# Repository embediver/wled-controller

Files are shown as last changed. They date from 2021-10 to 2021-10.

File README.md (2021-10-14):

# A simple, ESP-07 based, controller for NeoPixel LED's 
Designed to work with all kinds of single wire adressable NeoPixel LEDs and ATX Power supplies.

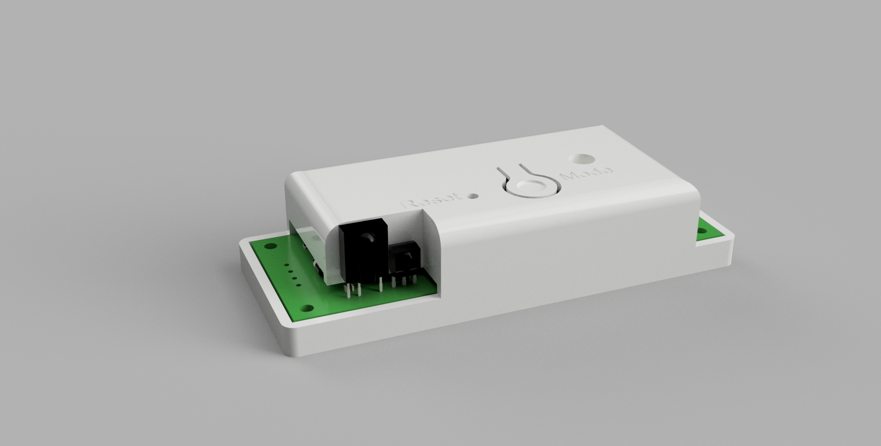
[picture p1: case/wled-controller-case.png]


* Works great with [WLED](https://github.com/Aircoookie/WLED)
* Support for IR Remotes
* Two-Layer PCB designed for home production
* 74HTC00 as Levelshifter
* Output to Toggle PS-ON pin of ATX power supplies
* Over voltage protection on I/O ports

It's intended to be uesed with ATX power supplies (since they are so easy availible), where it can be driven over the 5V always-on rail.
By powering the LED's with the other Rails, they can be switched off together with the PS.

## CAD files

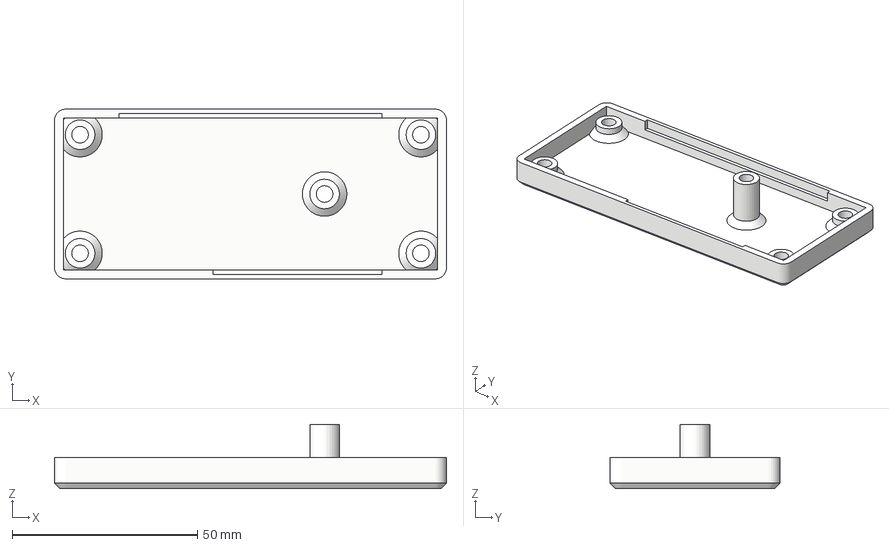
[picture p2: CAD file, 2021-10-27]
case/bottom.3mf
105.8 x 45.8 x 17.4 mm

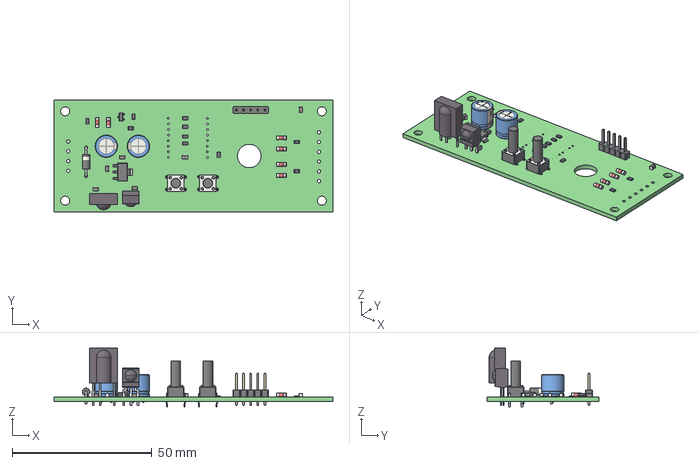
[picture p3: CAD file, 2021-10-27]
wled-controller.step
100.0 x 40.0 x 21.0 mm

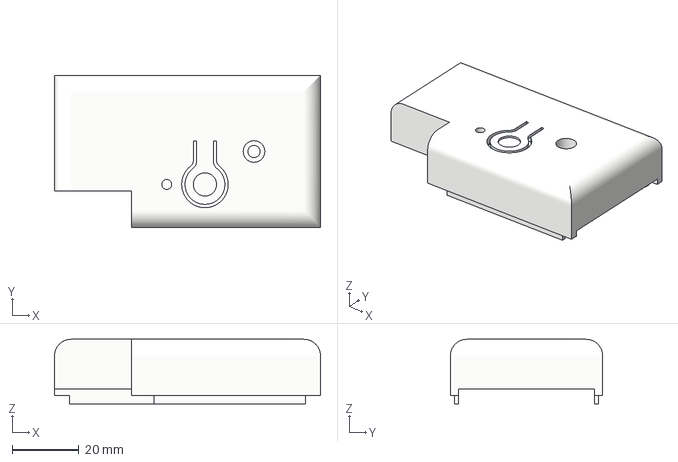
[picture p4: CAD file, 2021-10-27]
case/cover.3mf
80.0 x 45.8 x 19.4 mm

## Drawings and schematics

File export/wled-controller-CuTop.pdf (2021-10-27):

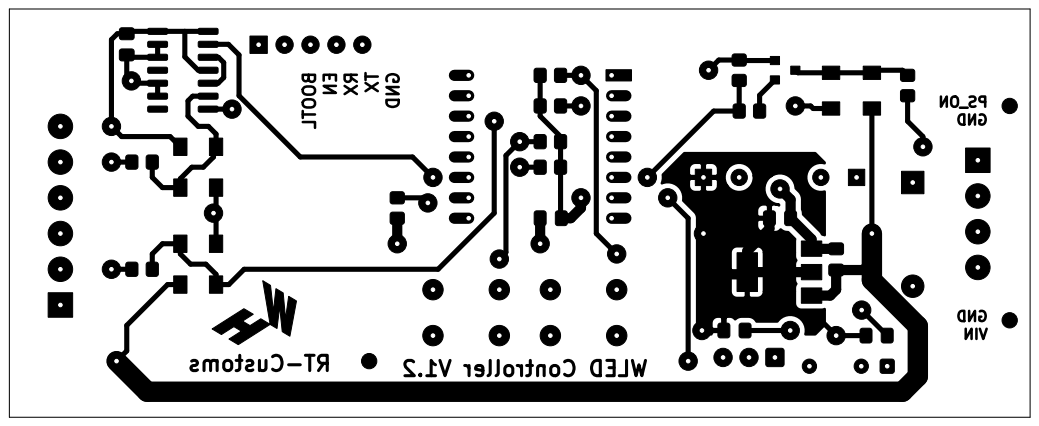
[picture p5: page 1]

PS_ON GND RT-Customs WLED Controller V1.2 BOOTL ENRXTXGND

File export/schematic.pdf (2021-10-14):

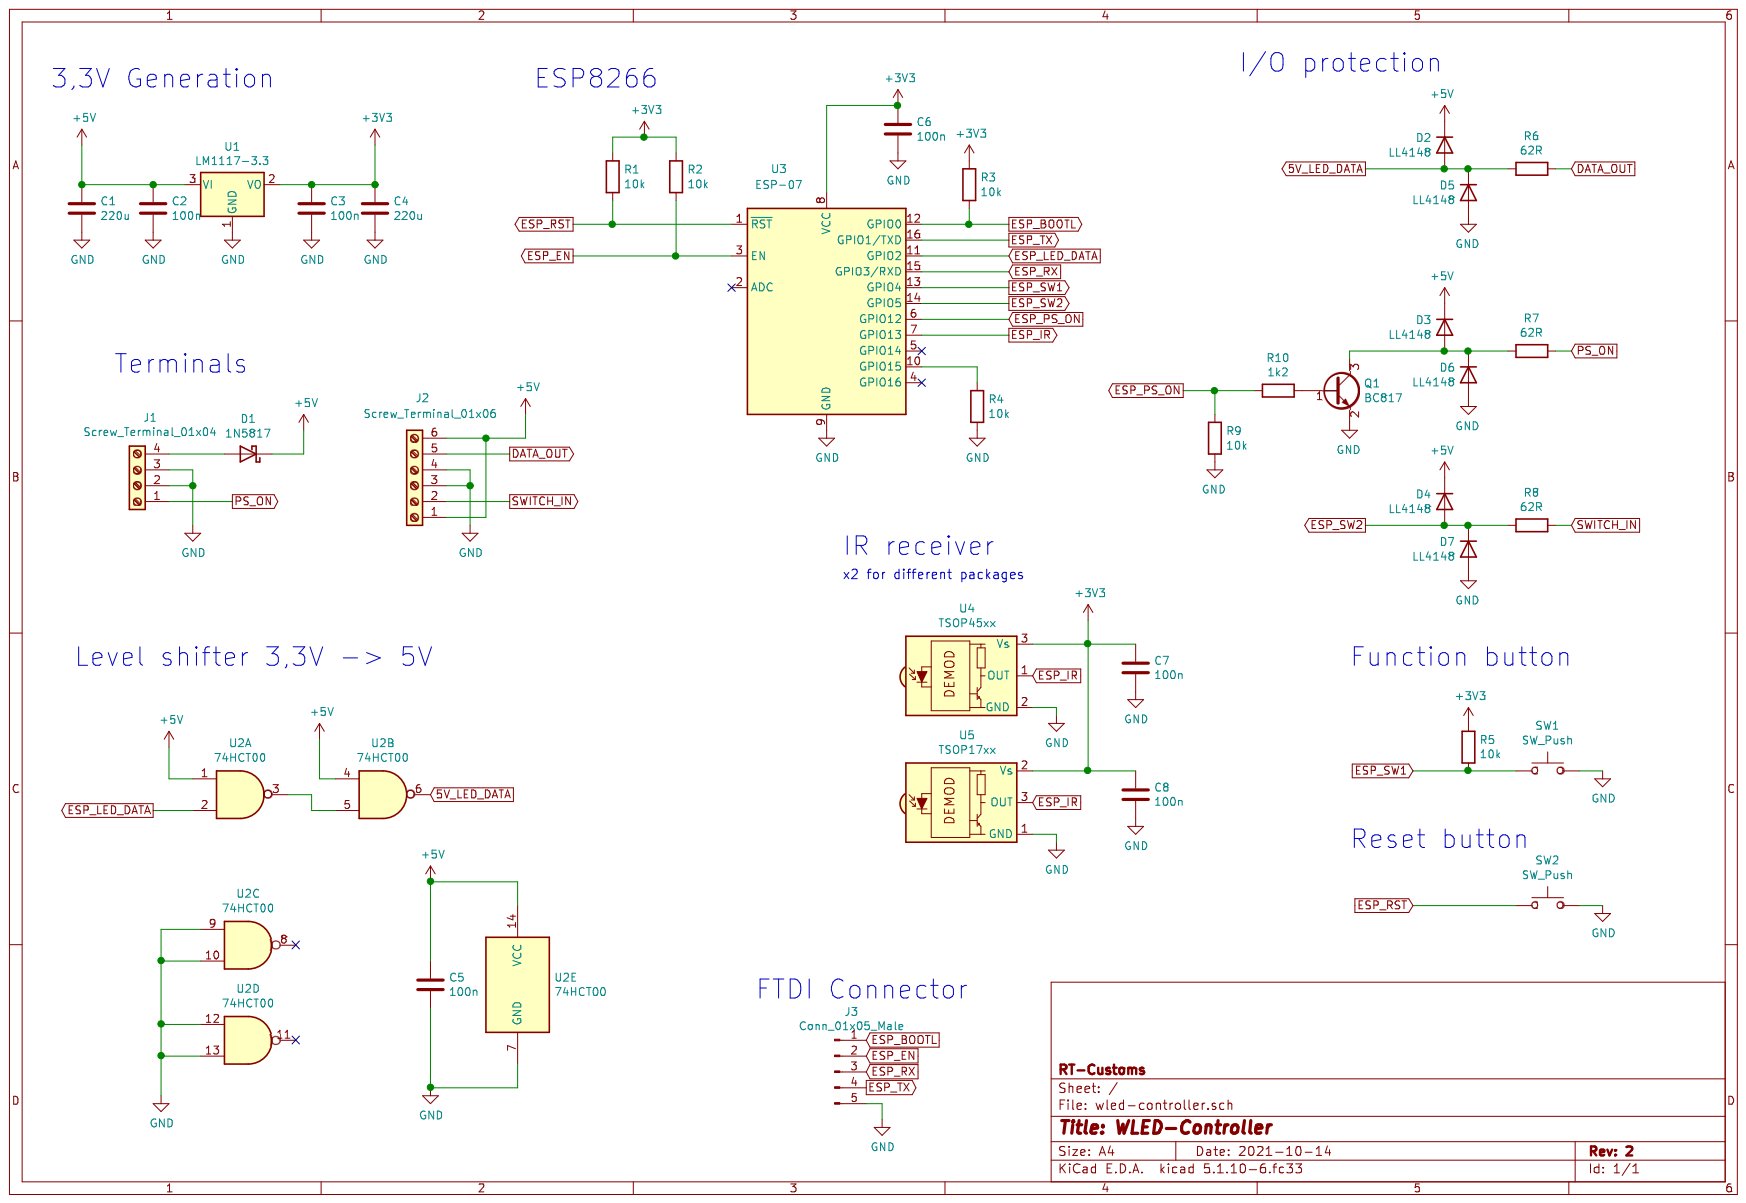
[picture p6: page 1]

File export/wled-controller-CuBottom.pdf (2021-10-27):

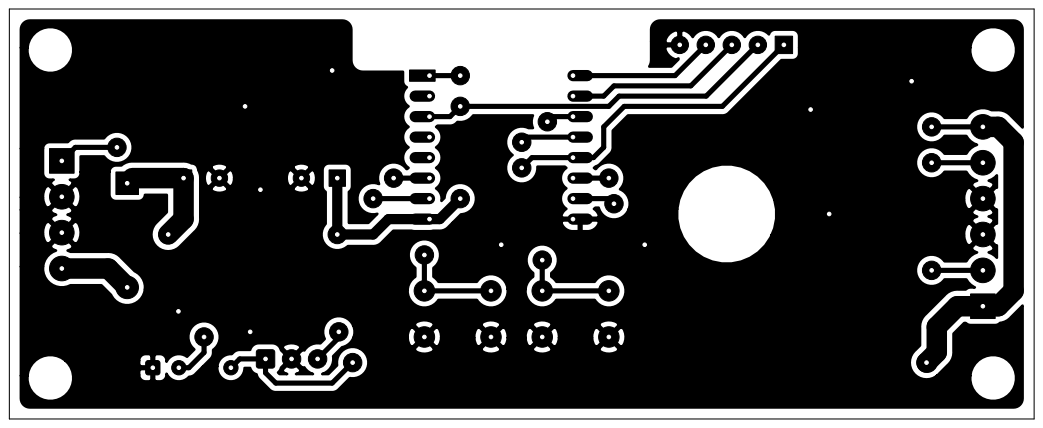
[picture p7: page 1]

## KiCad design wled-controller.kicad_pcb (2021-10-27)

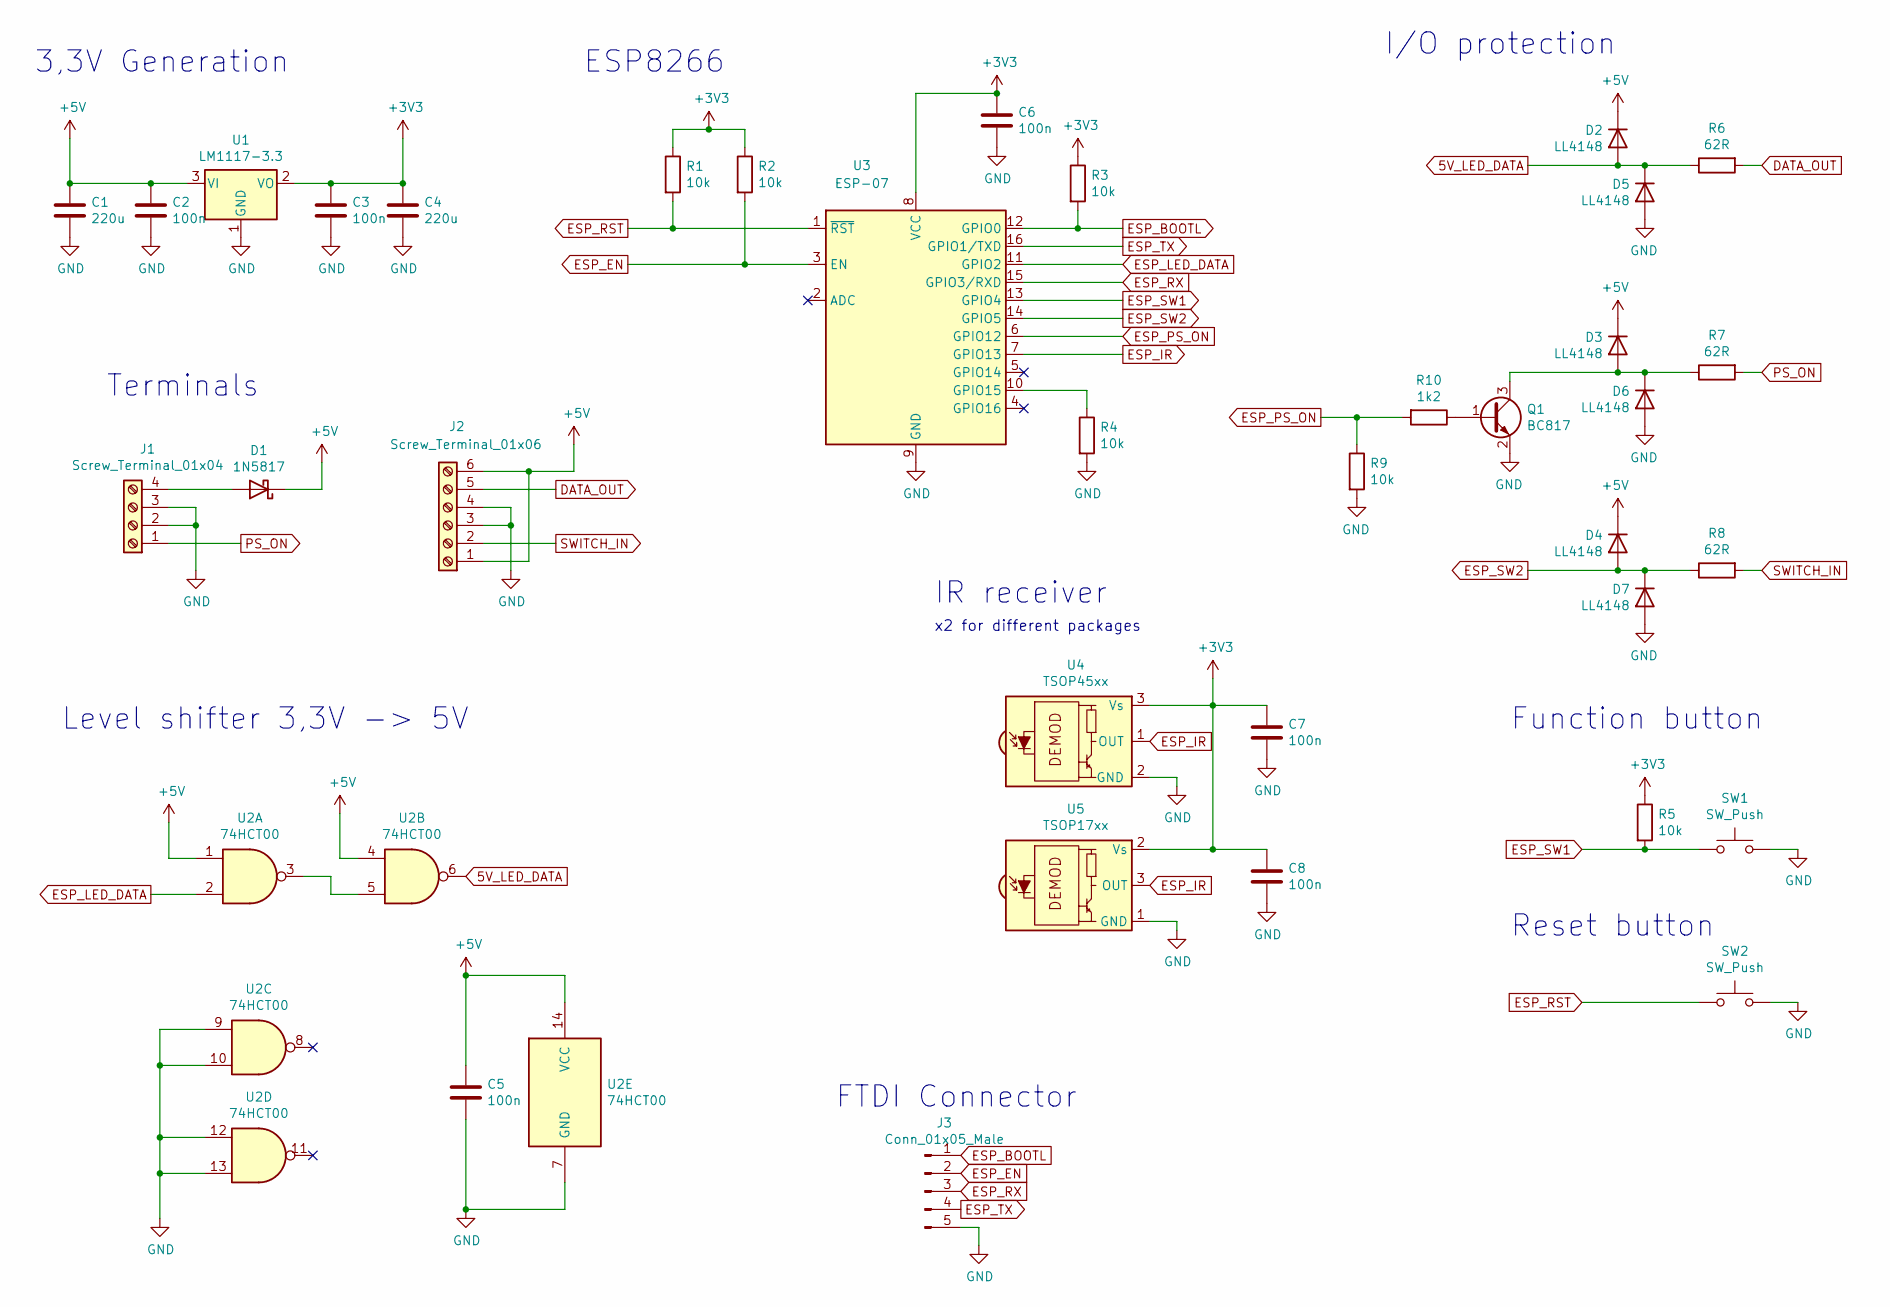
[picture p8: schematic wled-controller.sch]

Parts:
C1, C4: 220u; CP_Radial_D8.0mm_P3.50mm
C2, C3, C5, C6, C7, C8: 100n; C_0805_2012Metric_Pad1.18x1.45mm_HandSolder
D1: 1N5817; D_DO-41_SOD81_P10.16mm_Horizontal
D2, D3, D4, D5, D6, D7: LL4148; D_MiniMELF
J1: Screw_Terminal_01x04; TerminalBlock_4Ucon_1x04_P3.50mm_Horizontal
J2: Screw_Terminal_01x06; TerminalBlock_4Ucon_1x06_P3.50mm_Horizontal
J3: Conn_01x05_Male; PinHeader_1x05_P2.54mm_Vertical
Q1: BC817; SOT-23
R1, R2, R3, R4, R5, R9: 10k; R_0805_2012Metric_Pad1.20x1.40mm_HandSolder
R6, R7, R8: 62R; R_0805_2012Metric_Pad1.20x1.40mm_HandSolder
R10: 1k2; R_0805_2012Metric_Pad1.20x1.40mm_HandSolder
SW1, SW2: SW_Push; SW_PUSH_6mm_H13mm
U1: LM1117-3.3; SOT-223-3_TabPin2
U2: 74HCT00; SO-14_3.9x8.65mm_P1.27mm
U3: ESP-07; ESP-07v2
U4: TSOP45xx; Vishay_MOLD-3Pin
U5: TSOP17xx; Vishay_CAST-3Pin

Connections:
5V_LED_DATA: D2.2 (A), D5.1 (K), R6.1, U2.6
+3V3: C3.1, C4.1, C6.1, C7.1, C8.1, R1.1, R2.1, R3.1, R5.1, U1.2 (VO), U3.8 (VCC), U4.3 (Vs), U5.2 (Vs)
+5V: C1.1, C2.1, C5.1, D1.1 (K), D2.1 (K), D3.1 (K), D4.1 (K), J2.1, J2.6, U1.3 (VI), U2.1, U2.4, U2.14 (VCC)
DATA_OUT: J2.5, R6.2
ESP_BOOTL: J3.1, R3.2, U3.12 (GPIO0)
ESP_EN: J3.2, R2.2, U3.3 (EN)
ESP_IR: U3.7 (GPIO13), U4.1 (OUT), U5.3 (OUT)
ESP_LED_DATA: U2.2, U3.11 (GPIO2)
ESP_PS_ON: R9.1, R10.2, U3.6 (GPIO12)
ESP_RST: R1.2, SW2.1, U3.1 (~RST)
ESP_RX: J3.3, U3.15 (GPIO3/RXD)
ESP_SW1: R5.2, SW1.1, U3.13 (GPIO4)
ESP_SW2: D4.2 (A), D7.1 (K), R8.1, U3.14 (GPIO5)
ESP_TX: J3.4, U3.16 (GPIO1/TXD)
GND: C1.2, C2.2, C3.2, C4.2, C5.2, C6.2, C7.2, C8.2, D5.2 (A), D6.2 (A), D7.2 (A), J1.2, J1.3, J2.3, J2.4, J3.5, Q1.2 (E), R4.2, R9.2, SW1.2, SW2.2, U1.1 (GND), U2.7 (GND), U2.9, U2.10, U2.12, U2.13, U3.9 (GND), U4.2 (GND), U5.1 (GND)
unnamed: D1.2 (A), J1.4
unnamed: D3.2 (A), D6.1 (K), Q1.3 (C), R7.1
unnamed: Q1.1 (B), R10.1
unnamed: R4.1, U3.10 (GPIO15)
unnamed: U2.3, U2.5
PS_ON: J1.1, R7.2
SWITCH_IN: J2.2, R8.2

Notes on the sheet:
3,3V Generation
ESP8266
Function button
Reset button
IR receiver
x2 for different packages
Level shifter 3,3V -> 5V
I/O protection
Terminals
FTDI Connector

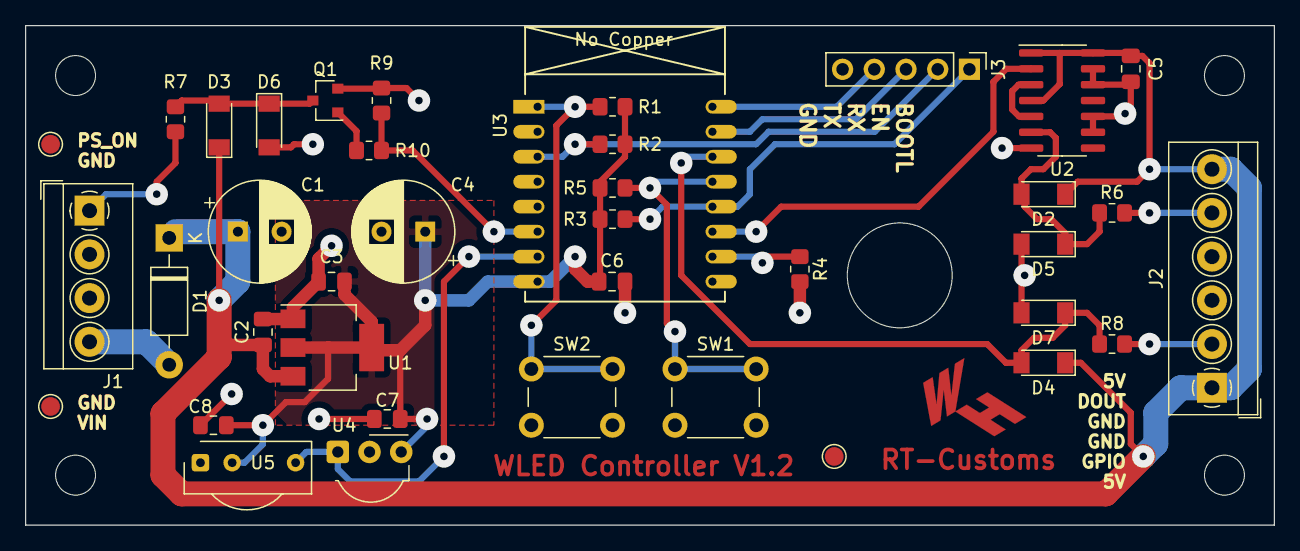
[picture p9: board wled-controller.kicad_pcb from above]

Board: 2 copper layers, 100.0 x 40.0 mm, 36 parts (0 on the bottom side), 22 nets.

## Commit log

2021-10-08 First routing.
    [wled-controller.sch]
2021-10-11 Rev 2 with open Collector PS switch
    [wled-controller.kicad_pcb, wled-controller.sch]
2021-10-11 Moved ESP to not stick over board side.
    [wled-controller.kicad_pcb, wled-controller.step]
2021-10-11 .3mf case files.
    And minor silkscreen improvement.
    [bottom.3mf, cover.3mf, wled-controller.kicad_pcb]
2021-10-11 Fix unconnected pad & silkscreen placement
    [wled-controller.kicad_pcb]
2021-10-12 Generated RT-Lab manufactoring data.
    [wled-controller-B_Cu.gbr, wled-controller-Eco1_User.gbr, wled-controller-Edge_Cuts.gbr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]
2021-10-12 Changed input diode to 1N5817.
    [wled-controller.kicad_pcb, wled-controller.sch]
2021-10-13 Minor improvements.
    [wled-controller.kicad_pcb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]
2021-10-13 Changed programming header to 2.54mm
    [bottom.3mf, cover.3mf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]
2021-10-14 Added README and schematic pdf
    [wled-controller.sch]
2021-10-27 Reduced board length to 100mm.
    Improved and added Silkscreen features.
    [bottom.3mf, cover.3mf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]
